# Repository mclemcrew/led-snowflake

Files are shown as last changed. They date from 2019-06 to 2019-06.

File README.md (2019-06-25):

# LED-Snowflake :snowflake:
This Christmas decoration was made with the intent of mass producing these for friends/family.  Didn't necessarily turn out that way...but I ended up building around 15 or so for friends/family during Christmas 2018 :christmas_tree:

Muli-Color Image of LED Sculpture







## Getting Started

Due to the nature of this project, the code isn't necessarily transferrable to other domains unless you built an LED Snowflake as well (and if you've built a similar project I would love to see what you created! :smile: )

## Built With

* [Arduino Nano] - The microcontroller used
* [WS2812B RGB 5050 LED Strip] – LEDs inside the snowflake

## CAD Files

The necessary STL files are provided in the docs so you can print your own snowflake!  Feel free to modify it how you see fit :smile:

## Directions

Currently, the directions are laid out in a PDF so you can download them at your lesiure and take them with you wherever you build it.  Everything should be explained thoroughly, but if you have some questions or whatnot, feel free to drop a comment and let me know!

## Authors

* **Michael Clemens (mclemcrew)**

## License

This project is licensed under the MIT License - see the [LICENSE.md](LICENSE.md) file for details

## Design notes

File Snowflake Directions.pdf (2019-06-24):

Directions for Arduino Nano Snowflake

Supplies:
- Arduino Nano (comes with 3 and you only need one for each snowflake) -https://www.amazon.com/gp/product/B0713XK923/ref=oh_aui_detailpage_o00_s00?ie=UTF8&psc=1
- WS2812 (LEDs) (comes with 420 LEDs and you need 36 for each snowflake) -https://www.amazon.com/gp/product/B00K7UHPEC/ref=oh_aui_detailpage_o00_s00?ie=UTF8&psc=1
- 9 Volt battery -
https://www.amazon.com/gp/product/B00MH4QM1S/ref=oh_aui_detailpage_o00_s00?ie=UTF8&psc=1
- 22 AWG stranded hook-up wire (I would recommend getting three spools with a different color each. One for power lines, the second for ground, and the third for data lines -
https://www.amazon.com/gp/product/B00NB3SQJU/ref=oh_aui_detailpage_o02_s00?ie=UTF8&psc=1
- eSUN 3 mm Cool White PLA (I have about enough to print 10 or so of these on one spool so one should be totally cool) -https://www.amazon.com/gp/product/B01EKFV60S/ref=oh_aui_detailpage_o04_s00?ie=UTF8&psc=1
- Push button (comes with 20 and you need 2 per snowflake) -https://www.amazon.com/gp/product/B01ER729Y6/ref=oh_aui_detailpage_o03_s00?ie=UTF8&psc=1
- SPDT switches (comes with 10 and you need 1 per snowflake) -https://www.amazon.com/gp/product/B01N7NCW8N/ref=oh_aui_detailpage_o03_s00?ie=UTF8&psc=1
- 9V battery snap connector (comes with 10 and you need 1 per snowflake) -https://www.amazon.com/BBTO-Battery-Connector-Cable-Connection/dp/B0779ZSNS3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

Other things you will need:
- Access to 3D printer
- Access to soldering equipment
- Wire stripper/wire cutter
- Hot Glue Gun
- Velcro

Directions:

Get Case Ready for Soldering:

1. Using the 3D printing materials available to you, print out the full design which includes:
a. Base Plate
b. Backing Plate
c. Half Box with wire cutout
d. Cover with switch and push button cutouts
e. Battery Cover
2. Cut 6 strips of LEDs with 4 LEDs per strip
3. Glue the LED strips to the Base Plate for the snowflakes with the data line pointing in towards the center of the piece (obviously make sure these are upside down meaning that the LEDs are pointing outwards and fit into the squares. This seems obvious…but just make sure)
a. Start gluing from the furthest most LED from the center and continue on to the center
b. Bend the top of the LED strip (furthest away from the center) back so that the lettering on the copper strips are exposed. The reason for doing this is because I’ve found that the top of the copper pads for the DI/DO traces tend to be a lot more reliable than the underside of the WS2812s.
c. Get rid of all the excess glue by cutting it away or just ripping it out. Make sure that the LED strip is laying as flat as possible against the base plate.

Prepare Wires for Soldering:

1. Cut wires to appropriate lengths
a. 6 (1 ½’’) wires for connecting DI/DO
b. 5 (1/2’’) wires for connecting power
c. 5 (1/2’’) wires for connecting ground
d. 1 (1 ½’’) wire for connecting power
e. 1 (1 ½’’) wire for connecting ground
f. 2 (3/4’’) wire for connecting buttons to Arduino
g. 1 (1 ¼’’) wire for connecting grounds of buttons
h. 1 (3/4’’) wire for connecting button ground to Arduino ground
2. Strip both ends of all the wires
3. Tin all of the wires
a. Since we went with shredded wires, you’re going to have to “tin” the wires. Be leery to tin the ends that are going into the Arduino with extreme care. These will have to fit in incredibly small pockets so if your tinning isn’t the best, you might want to leave these ends without any solder so that you might have a better chance of getting a good soldering joint at the connection with the Arduino.

Prepare LED strips for Soldering:
1. You will need to “tin” all of the copper pads that are going to be soldered too. If you forget this step, it becomes nearly impossible to solder to these LED strips. They definitely aren’t the easiest things to solder, so all of the tinning will help in the long run for ensuring a solid solder joint. Follow the diagram below to know what parts of the strip to solder. Remember that at the outmost part of the LED strip you are going to be soldering the top of the LED strip for DO rather than the underside which is what you normally will see.

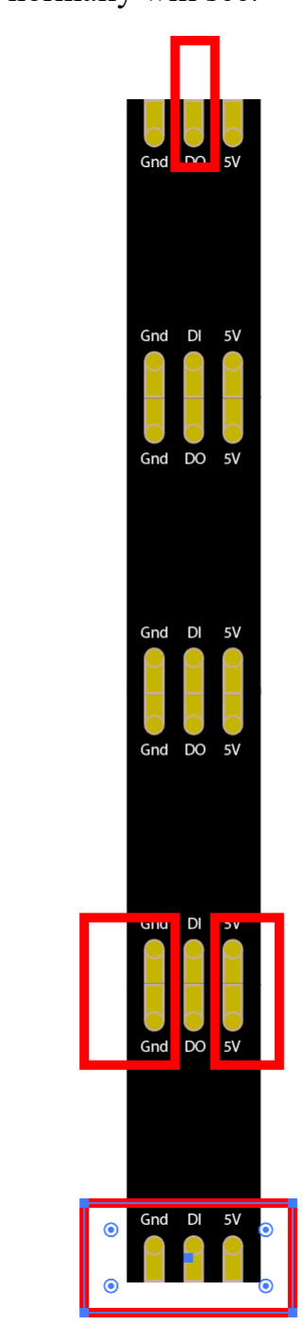
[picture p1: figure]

Solder up the Base Plate:

1. You will be using the wires from the list up above highlighted in orange in order to accomplish this part of the directions. I would start by soldering all of the DO/DIs together first. The diagram for that will look like this:

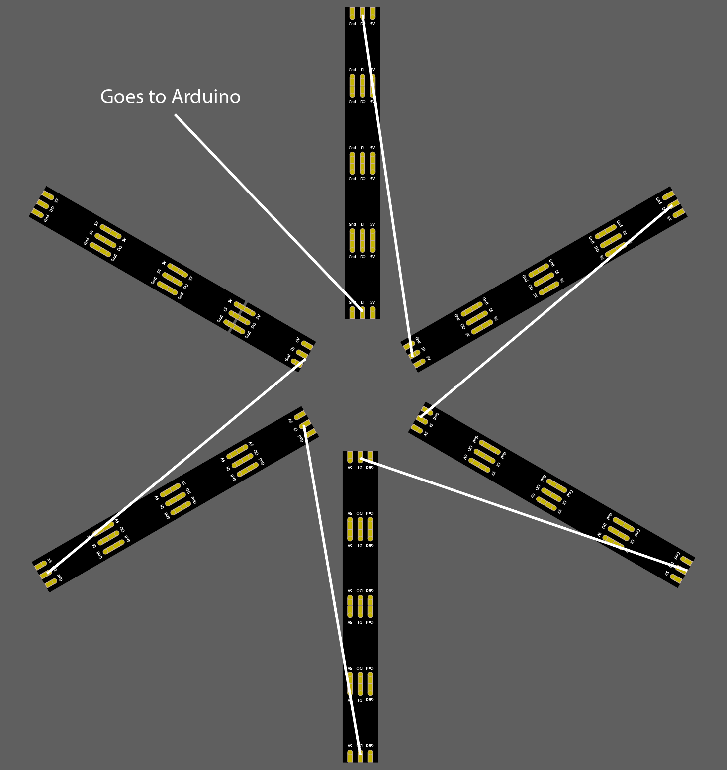
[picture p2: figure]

2. Next, you will be wiring up the power on the same strips. The diagram will look something like this:

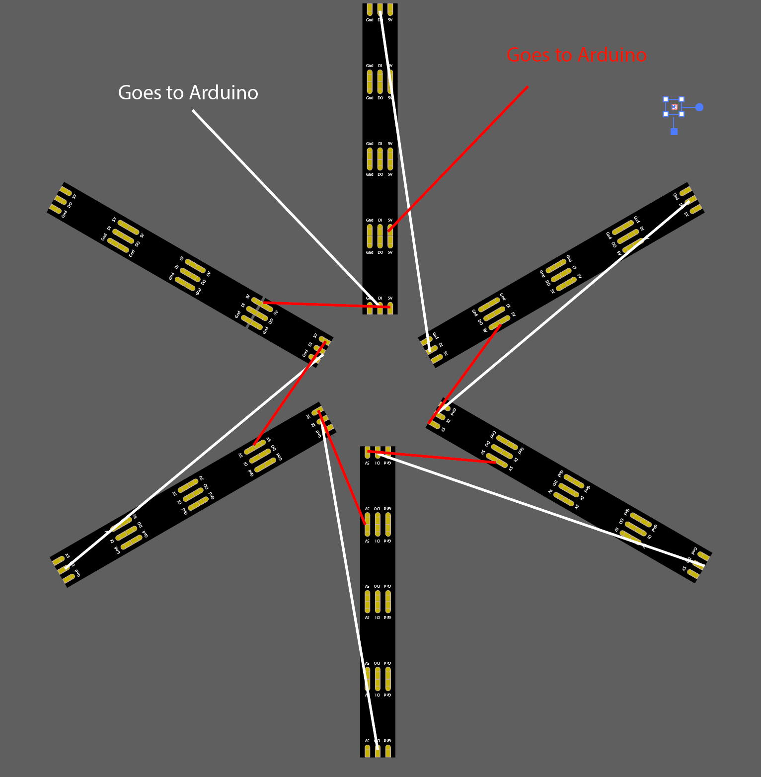
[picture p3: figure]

3. Now for the ground wires. Same deal as the power lines. I would use black wires to hook up the ground wires, but in the image, I used an aqua color so that it would be easier to see.

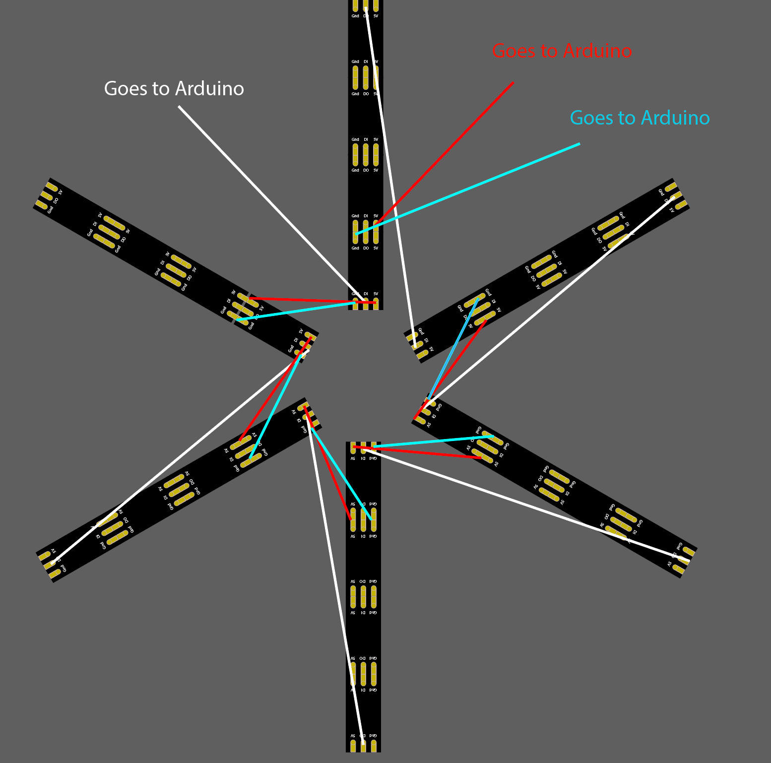
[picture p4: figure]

4. Now for the wires that say, “Goes to Arduino”, make sure those are the long wires, not the shorter ones that you’re using. These will in fact go to the Arduino through the back plate…that’s why they need the extra length…in order to actually make it to the Arduino.

Prepare the Controller:
1.) Grab the plate with the slits for the push buttons and switches and glue the push buttons and the switch into place. Ensure that you have the orientation of the push buttons correct. If you look closely at the push buttons, there are 4 prongs: 2 sets of 2 that are electrically connected. The diagram for this looks something like this:

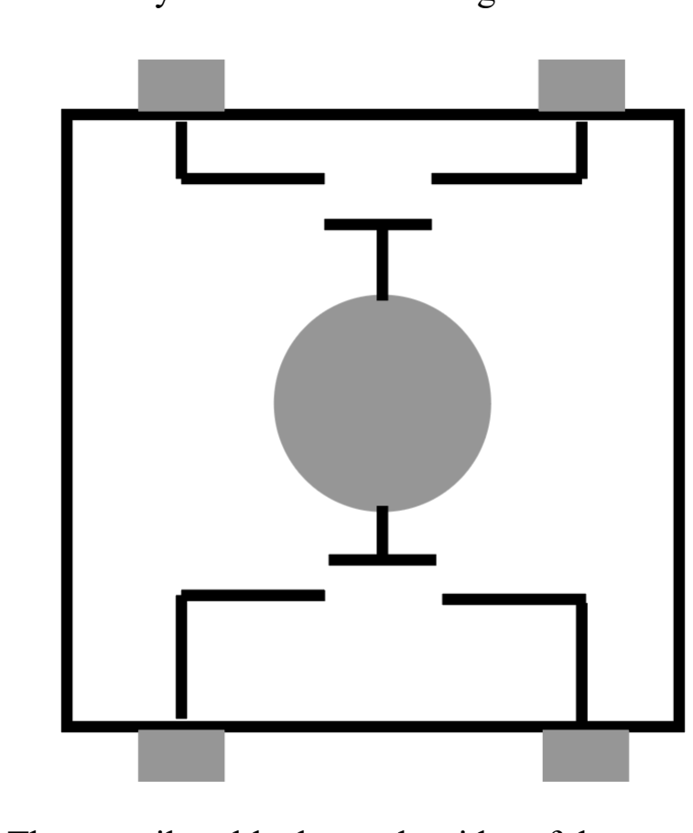
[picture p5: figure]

The two silver blocks on the sides of the square are the pins for the push button. These are the ones that are electronically connected to one another. I drew the circuit diagram essentially to show that when you depress the push button, there is a little metal piece that comes down and connects the two sides together…. thus, electrically connecting them. Make sure whatever way you glue the push buttons together you are VERY AWARE of this. If you don’t know what you’re doing here, the push buttons simply won’t
work…and we definitely don’t want that. I’ll try to be as explicit as possible about the orientation from here on out…but make sure you are taking heed as well.

2.) Solder this baby up, but not the entire thing yet. We are going to just do the main controller part that doesn’t have to do with the Arduino. So, grab the 9V snap connector along with some wires (the rest of the ones we haven’t used) and away we go! Here’s what the connections should look like current on the controller part from underneath. This part is tricky so heads up:

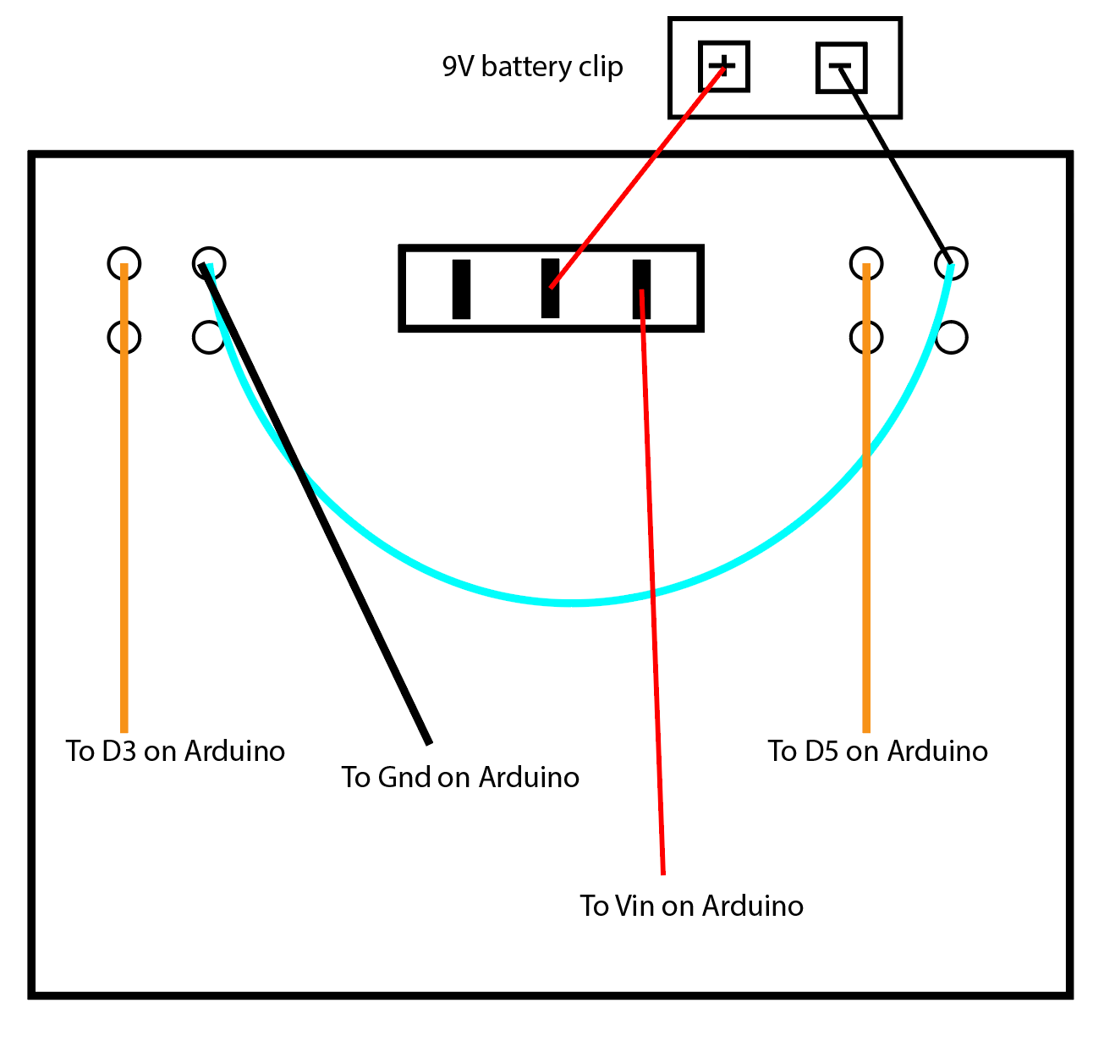
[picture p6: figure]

Prepare the Arduino:

Kyli should have this code, but you’re going to want to flash the Arduino with the code provided. Make sure you do this step before soldering to the Arduino…otherwise with all the wires, doing this becomes incredibly tedious.

Finish the Soldering Work:

Now for everything where I donated: “To … on Arduino”, you’re going to want to solder all of those connections now. From the LED strips take the 3 wires (one data, one power, and one ground) and feed them through the back plate and then the box that will house all the wires. Once that’s done, solder those wires up as follows:

Arduino -----> LED Strip
D12 | Data
5V | Power
Gnd | Ground

Make it Look Pretty:

You should now be done with the electronic part of the project (objectively the most difficulty aspect of the project). Make sure all of it works with the switch, push buttons, etc. If it doesn’t work now…it’s not going to work after this step…SO BE SURE THE THING ACTUALLY WORKS!

Now, what you want to do is glue the backing to the LED strips. I would just put some hot glue on the end of the DO solder joints from the strips and press the backing plate down until it stays there securely. Next would be to glue the box to the backing plate. Again, just make sure you have enough hot glue to make it stationary, and then you should be good to go! After that, glue the controller plate onto the box, again with hot glue. Last part is the plain cover (this will be used for getting the 9V battery in and out). What I ended up doing was using Velcro on the 4 corners so that you can just peel the plate away when needed. Make sure that however the orient the snowflake, that plate is on top, otherwise gravity will take hold and most likely rip the battery out of the snowflake and destroy some of your perfectly crafted solder joints D:

Celebrate:

YOU DONE DID IT! CONGRATULATIONS! (Make sure it still works after all the glue…it should…but I’ve definitely worked on projects where the last step caused everything to fail miserably)

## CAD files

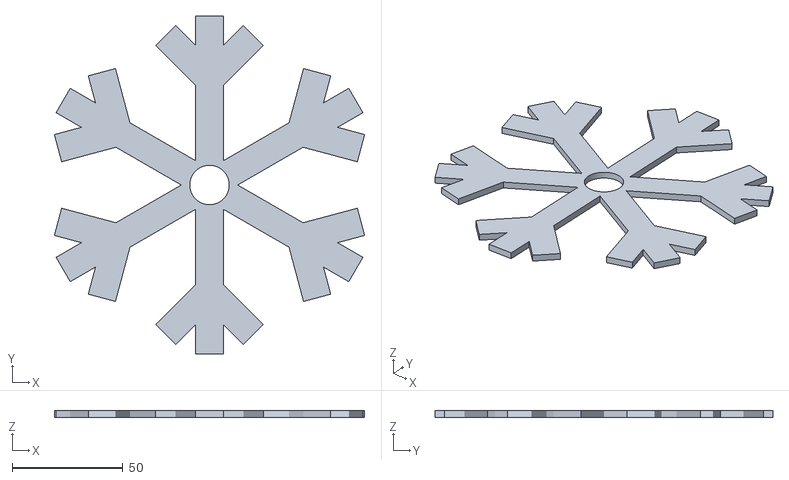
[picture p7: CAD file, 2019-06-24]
Snowflake Design/Main Snowflake.stl
139.9 x 152.4 x 3.05

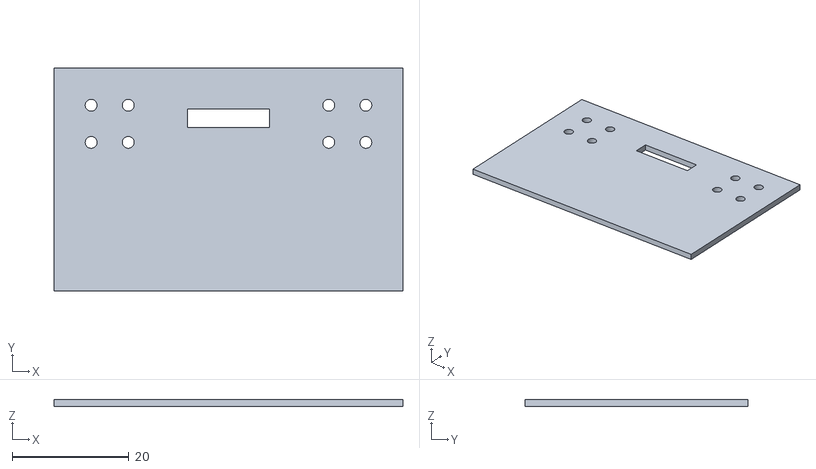
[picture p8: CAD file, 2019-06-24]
Snowflake Design/Top Side Piece.stl
59.7 x 38.1 x 1.27

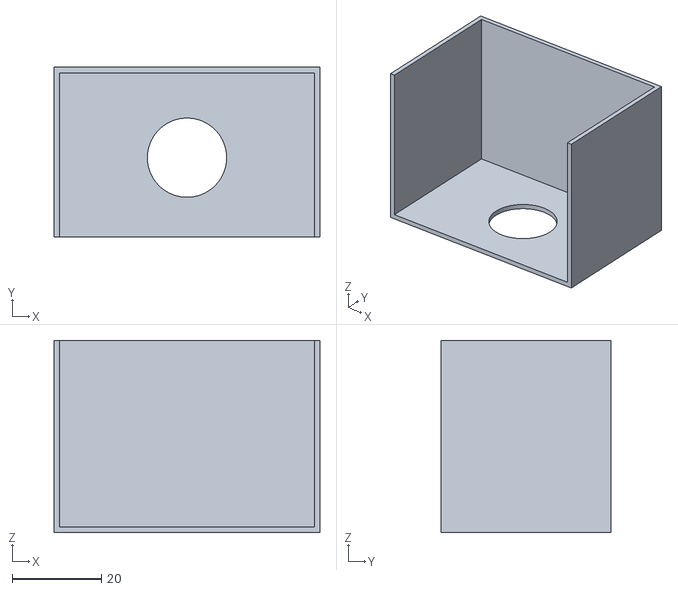
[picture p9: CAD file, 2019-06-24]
Snowflake Design/Cover for light enclosure.stl
59.7 x 38.1 x 43.2

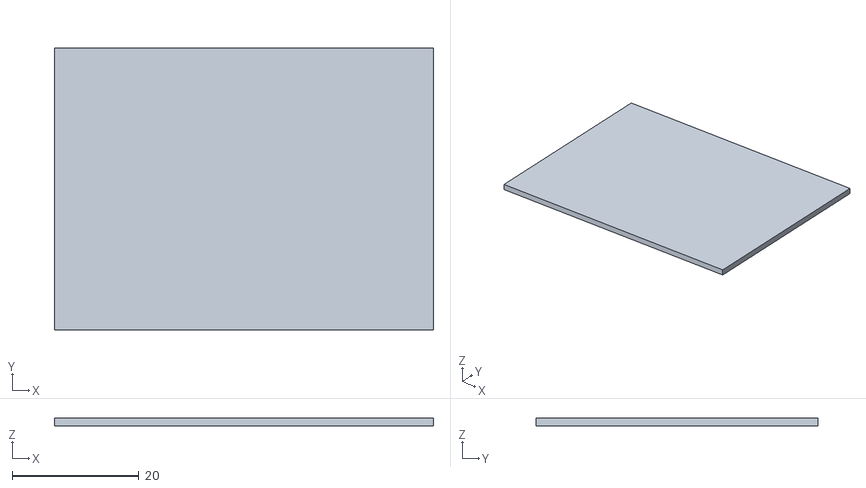
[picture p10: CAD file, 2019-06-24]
Snowflake Design/Battery Holder.stl
59.7 x 44.4 x 1.27

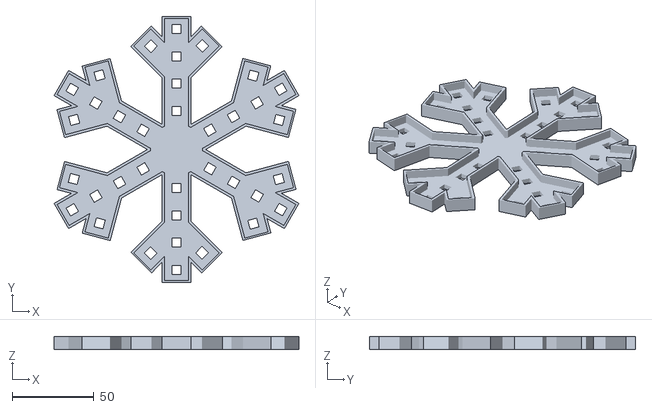
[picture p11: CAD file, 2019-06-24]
Snowflake Design/Cover Snowflake.stl
149.7 x 162.6 x 8.13

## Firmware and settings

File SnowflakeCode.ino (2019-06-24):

// This is a demonstration on how to use an input device to trigger changes on your neo pixels.
// You should wire a momentary push button to connect from ground to a digital IO pin.  When you
// press the button it will change to a new pixel animation.  Note that you need to press the
// button once to start the first animation!

#include <Adafruit_NeoPixel.h>

#define BUTTON_PIN_1   3    // Digital IO pin connected to the button.  This will be
                          // driven with a pull-up resistor so the switch should
                          // pull the pin to ground momentarily.  On a high -> low
                          // transition the button press logic will execute.
#define BUTTON_PIN_2  5

#define PIXEL_PIN    12    // Digital IO pin connected to the NeoPixels.

#define PIXEL_COUNT 24

Adafruit_NeoPixel strip = Adafruit_NeoPixel(PIXEL_COUNT, PIXEL_PIN, NEO_GRB + NEO_KHZ800);

bool oldState1 = HIGH;
bool oldState2 = HIGH;
bool newState1 = HIGH;
bool newState2 = HIGH;
int colorIndicator = 0;
int showIndicator = 0;

void setup() {
  pinMode(BUTTON_PIN_1, INPUT_PULLUP);
  pinMode(BUTTON_PIN_2, INPUT_PULLUP);
  strip.begin();
  strip.show(); // Initialize all pixels to 'off'
  colorType(0);
  showType(0);
}

void loop() {
  // Get current button state.
  newState1 = digitalRead(BUTTON_PIN_1);
  newState2 = digitalRead(BUTTON_PIN_2);

  // Check if state changed from high to low (button press).
  if (newState1 == LOW && oldState1 == HIGH) {
    // Short delay to debounce button.
    delay(15);
    // Check if button is still low after debounce.
    newState1 = digitalRead(BUTTON_PIN_1);
    if (newState1 == LOW) {
      colorIndicator++;
      if (colorIndicator > 3)
        colorIndicator=0;
      oldState1 = newState1;
      colorType(colorIndicator);
    }
  }

  if (newState2 == LOW && oldState2 == HIGH) {
    // Short delay to debounce button.
    delay(15);
    // Check if button is still low after debounce.
    newState2 = digitalRead(BUTTON_PIN_2);
    if (newState2 == LOW) {
      showIndicator++;
      if (showIndicator > 3)
        showIndicator=0;
      oldState2 = newState2;
      showType(showIndicator);
    }
  }

  // Set the last button state to the old state.
  oldState1 = newState1;
  oldState2 = newState2;
}

void colorType(int i) {
  switch(i){
    case 0: 
      if(showIndicator==0) {
        solid(0, 50); 
      }  
      if(showIndicator==1) {
        theaterChase(0, 120);
      }
      break;
    case 1:
      if(showIndicator==0) {
        solid(1, 50); 
      }  
      if(showIndicator==1) {
        theaterChase(1, 120);
      }
      break;
    case 2: 
      if(showIndicator==0) {
        solid(2, 50); 
      }  
      if(showIndicator==1) {
        theaterChase(2, 120);
      }
      break;
    case 3: 
      if(showIndicator==0) {
        solid(3, 50); 
      }  
      if(showIndicator==1) {
        theaterChase(3, 120);
      }
      break;
  }
}

void showType(int i) {
  switch(i){
    case 0: 
      if(colorIndicator==0) {
        solid(0, 50); 
      }  
      if(colorIndicator==1) {
        solid(1, 50);
      }
      if(colorIndicator==2) {
        solid(2, 50); 
      }  
      if(colorIndicator==3) {
        solid(3, 50);
      }
      break;
    case 1: 
      if(colorIndicator==0) {
        theaterChase(0, 120); 
      }  
      if(colorIndicator==1) {
        theaterChase(1, 120);
      }
      if(colorIndicator==2) {
        theaterChase(2, 120); 
      }  
      if(colorIndicator==3) {
        theaterChase(3, 120);
      }
      break;
    case 2: rainbowCycle(30);
            break;
    case 3: rainbow(30);
            break;
  }
}

// Fill the dots one after the other with a color
void solid(uint8_t color, uint8_t wait) {
  if(color==0) {
    for(uint16_t i=0; i<strip.numPixels(); i=i+2) {
      strip.setPixelColor(i, strip.Color(0, 35, 180));
      delay(wait);
      strip.show();
    }
    for(uint16_t i=1; i<strip.numPixels(); i=i+2) {
      strip.setPixelColor(i, strip.Color(127, 127, 127));
      delay(wait);
      strip.show();
    }
  }
  if(color==1) {
    for(uint16_t i=0; i<strip.numPixels(); i=i+2) {
      strip.setPixelColor(i, strip.Color(127, 0, 0));
      delay(wait);
      strip.show();
    }
    for(uint16_t i=1; i<strip.numPixels(); i=i+2) {
      strip.setPixelColor(i, strip.Color(0, 127, 0));
      delay(wait);
      strip.show();
    }
  }
  if(color==2) {
    for(uint16_t i=0; i<strip.numPixels(); i=i+2) {
      strip.setPixelColor(i, strip.Color(160,120,16));
      delay(wait);
      strip.show();
    }
    for(uint16_t i=1; i<strip.numPixels(); i=i+2) {
      strip.setPixelColor(i, strip.Color(100,100,100));
      delay(wait);
      strip.show();
    }
  }
  if(color==3) {
    for(uint16_t i=0; i<strip.numPixels(); i=i+2) {
      strip.setPixelColor(i, strip.Color(170,30,0));
      delay(wait);
      strip.show();
    }
    for(uint16_t i=1; i<strip.numPixels(); i=i+2) {
      strip.setPixelColor(i, strip.Color(170,30,0));
      delay(wait);
      strip.show();
    }
  }
}

void rainbow(uint8_t wait) {
  uint16_t i, j;
  while(1){
  for(j=0; j<256; j++) {
    newState2 = digitalRead(BUTTON_PIN_2);

    if (newState2 == LOW && oldState2 == HIGH) {
      // Short delay to debounce button.
      delay(15);
      // Check if button is still low after debounce.
      newState2 = digitalRead(BUTTON_PIN_2);
      if (newState2 == LOW) {
        showIndicator++;
        if (showIndicator > 3)
          showIndicator=0;
        oldState2 = newState2;
        showType(showIndicator);
      }
      return;
    }
    for(i=0; i<strip.numPixels(); i++) {
      strip.setPixelColor(i, Wheel((i+j) & 255));
    }
    strip.show();
    delay(wait);
    oldState2 = newState2;
  }
  }
}

// Slightly different, this makes the rainbow equally distributed throughout
void rainbowCycle(uint8_t wait) {
  uint16_t i, j;
  while(1){
  for(j=0; j<256*5; j++) { // 5 cycles of all colors on wheel
    newState2 = digitalRead(BUTTON_PIN_2);

    if (newState2 == LOW && oldState2 == HIGH) {
      // Short delay to debounce button.
      delay(15);
      // Check if button is still low after debounce.
      newState2 = digitalRead(BUTTON_PIN_2);
      if (newState2 == LOW) {
        showIndicator++;
        if (showIndicator > 3)
          showIndicator=0;
        oldState2 = newState2;
        showType(showIndicator);
      }
      return;
    }
    for(i=0; i< strip.numPixels(); i++) {
      strip.setPixelColor(i, Wheel(((i * 256 / strip.numPixels()) + j) & 255));
    }
    strip.show();
    delay(wait);
    oldState2 = newState2;
  }
  }
}

//Theatre-style crawling lights.
void theaterChase(uint8_t color, uint8_t wait) {
  while (1) {  //do 10 cycles of chasing
  
    for (int q=0; q < 3; q++) {
      newState2 = digitalRead(BUTTON_PIN_2);

      if (newState2 == LOW && oldState2 == HIGH) {
        // Short delay to debounce button.
        delay(15);
        // Check if button is still low after debounce.
        newState2 = digitalRead(BUTTON_PIN_2);
        if (newState2 == LOW) {
          showIndicator++;
          if (showIndicator > 3)
            showIndicator=0;
          oldState2 = newState2;
          showType(showIndicator);
        }
        return;
      }
      if(color==0) {
        int change = 0;
        for(uint16_t i=0; i<strip.numPixels(); i=i+3) {
          if(change==0) {
            strip.setPixelColor(i+q, strip.Color(0, 35, 180));
            change = 1;
          }
          else {
            strip.setPixelColor(i+q, strip.Color(127, 127, 127));
            change = 0;
          }
        }   
      }
      if(color==1) {
        int change = 0;
        for(uint16_t i=0; i<strip.numPixels(); i=i+3) {
          if(change==0) {
            strip.setPixelColor(i+q, strip.Color(127, 0, 0));
            change = 1;
          }
          else {
            strip.setPixelColor(i+q, strip.Color(0, 127, 0));
            change = 0;
          }
        }   
      }
      if(color==2) {
        int change = 0;
        for(uint16_t i=0; i<strip.numPixels(); i=i+3) {
          if(change==0) {
            strip.setPixelColor(i+q, strip.Color(160,120,16));
            change = 1;
          }
          else {
            strip.setPixelColor(i+q, strip.Color(100, 100, 100));
            change = 0;
          }
        }   
      }
      if(color==3) {
        for(uint16_t i=0; i<strip.numPixels(); i=i+3) {
            strip.setPixelColor(i+q, strip.Color(170,30,0));
          }
       }   
      strip.show();
      delay(wait);

      for (int i=0; i < strip.numPixels(); i=i+3) {
        strip.setPixelColor(i+q, 0);        //turn every third pixel off
      }
      oldState2 = newState2;
    } 
  }
}

//Theatre-style crawling lights with rainbow effect
void theaterChaseRainbow(uint8_t wait) {
  for (int j=0; j < 256; j++) {     // cycle all 256 colors in the wheel
    for (int q=0; q < 3; q++) {
      for (int i=0; i < strip.numPixels(); i=i+3) {
        strip.setPixelColor(i+q, Wheel( (i+j) % 255));    //turn every third pixel on
      }
      strip.show();

      delay(wait);

      for (int i=0; i < strip.numPixels(); i=i+3) {
        strip.setPixelColor(i+q, 0);        //turn every third pixel off
      }
    }
  }
}

// Input a value 0 to 255 to get a color value.
// The colours are a transition r - g - b - back to r.
uint32_t Wheel(byte WheelPos) {
  WheelPos = 255 - WheelPos;
  if(WheelPos < 85) {
    return strip.Color(255 - WheelPos * 3, 0, WheelPos * 3);
  }
  if(WheelPos < 170) {
    WheelPos -= 85;
    return strip.Color(0, WheelPos * 3, 255 - WheelPos * 3);
  }
  WheelPos -= 170;
  return strip.Color(WheelPos * 3, 255 - WheelPos * 3, 0);
}
